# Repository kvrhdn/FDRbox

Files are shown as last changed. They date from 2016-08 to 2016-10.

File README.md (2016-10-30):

FDRbox
===
By Koenraad Verheyden - [@koenaad](https://twitter.com/koenaad)

Description
---
A simple USB MIDI controller with 8 faders.

[Album with images](http://imgur.com/a/iQqRE)

Status
---
I assembled a couple of boards and __they all work completely__!

TODO
* finish off design: find fadercaps, some screws and feet.
* clean up code.

Code
---
[```code/```](code/) is a subtree of [PIC16F145x_MIDI](https://github.com/koenaad/PIC16F145x_MIDI). The application specific code is in [```main.c```](code/main.c).

This project uses the USB stack from [Microchip Libraries for Applications](http://microchip.com/mla).  
MLA is licensed under the Apache License version 2.0. (See: [microchip.com/mla_license](http://microchip.com/mla_license))

PCB
---
[```pcb/```](pcb/) contains the schematics and design of the PCB. The entire PCB was designed using [KiCad](http://kicad-pcb.org/), an open-source software suite for EDA.

PDF's of the schematic are placed in [```pcb/output/```](pcb/output/).  
You can find the Gerber files I used here: [```pcb/output/FDRbox_v0.1_gerber/```](pcb/output/FDRbox_v0.1_gerber/)

Frontpanel
---
I also designed a frontpanel, [```frontpanel```](frontpanel/) contains the SVG I used to lasercut it.

Ableton Live MIDI Remote Script
---
[```Ableton Live MIDI Remote Script/```](Ableton Live MIDI Remote Script/) contains a MIDI Remote Script for Ableton Live. The script maps the faders to control the volume of the first 8 tracks.  
Using this script is not necessary to use FDRbox in Live (or any other DAW that supports MIDI controllers), all it does is automatically map the controls for you.

To install the script, please refer to [ableton.com: How to install a third-party Remote Script?
](https://www.ableton.com/en/help/article/install-third-party-remote-script/)

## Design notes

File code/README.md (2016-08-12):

PIC16F145x_MIDI
===
By Koenraad Verheyden - [@koenaad](https://twitter.com/koenaad)

Description
---
This project is meant to simplify designing USB MIDI controllers with the Microchip [PIC16F1454](http://www.microchip.com/wwwproducts/en/PIC16F1454) and [PIC16F1455](http://www.microchip.com/wwwproducts/en/PIC16F1455).

I chose the PIC16F145x becaues it is the smallest MCU I found capable of USB communication that doesn't need an external oscillator. [The TSSOP-14 version is really small indeed...](http://i.imgur.com/X8IG8gG.jpg)  
Additionally, Microchip sells a PDIP version which is easy to prototype with.

I made a small break-out board to experiment with this chip [[images](http://imgur.com/a/j5HQL)]. If there is interest, I am willing to post the KiCad files online or ship some of my spare PCBs.  
I'm planning to use this project as base for other MIDI controllers I design.

Usage
---
The ```system```-functions handle device initialization, configuring the USB MIDI stack and LED updates. User code can be added in ```main.c```. Usually no other files should be edited for simple applications.  
Keep in mind that no code inside the main loop may block.

To program the PIC you will probably need a [PICkit](http://www.microchip.com/Developmenttools/ProductDetails.aspx?PartNO=PG164130). Though, bootloaders could be an alternative.

MLA
---
This project uses the USB stack from [Microchip Libraries for Applications](http://microchip.com/mla).  
MLA is licensed under the Apache License version 2.0. (See: [microchip.com/mla_license](http://microchip.com/mla_license))

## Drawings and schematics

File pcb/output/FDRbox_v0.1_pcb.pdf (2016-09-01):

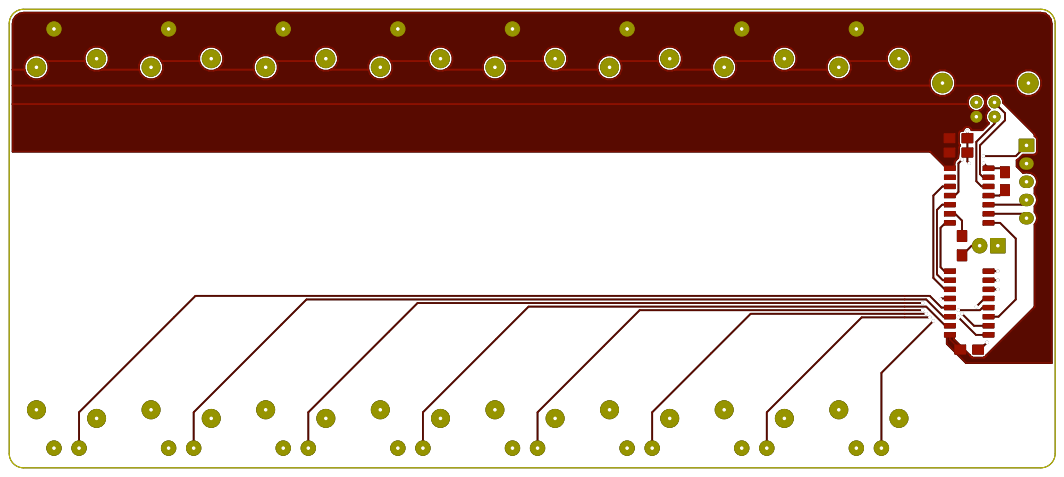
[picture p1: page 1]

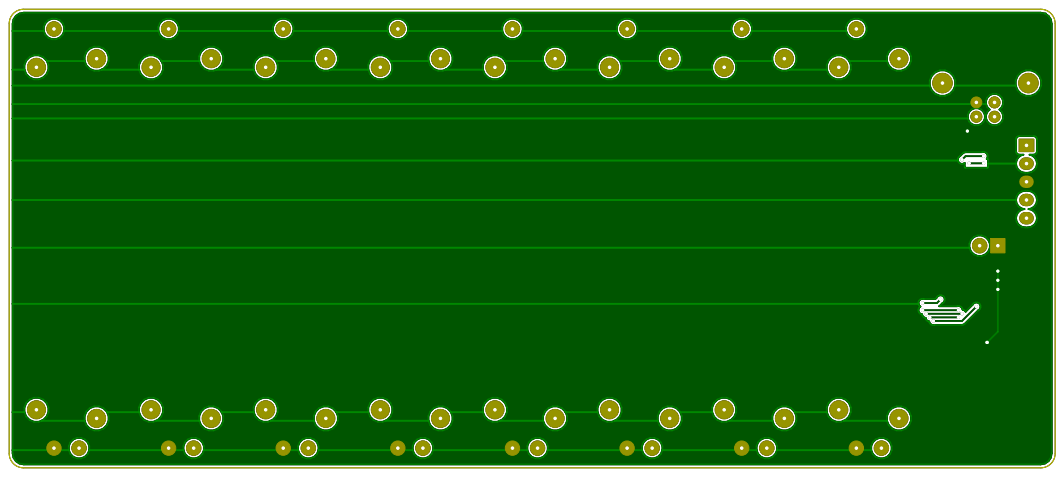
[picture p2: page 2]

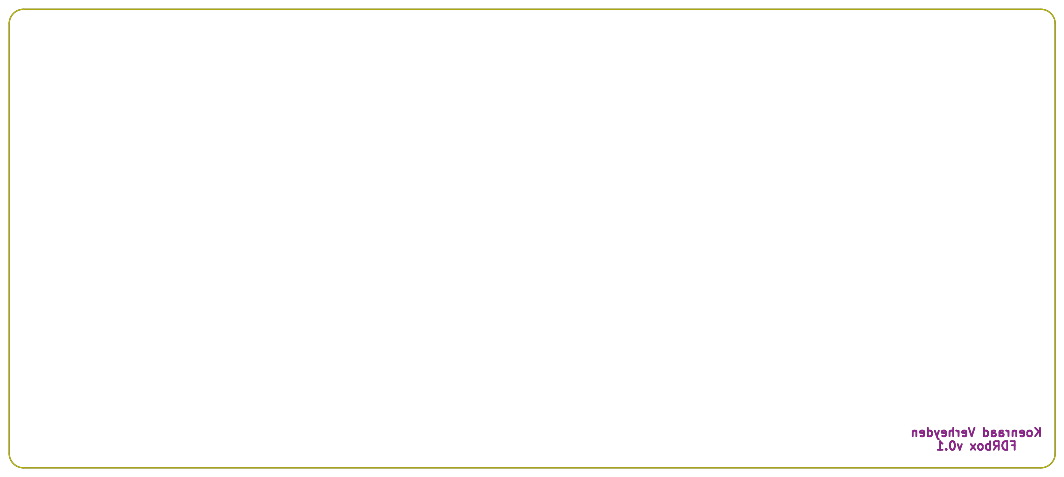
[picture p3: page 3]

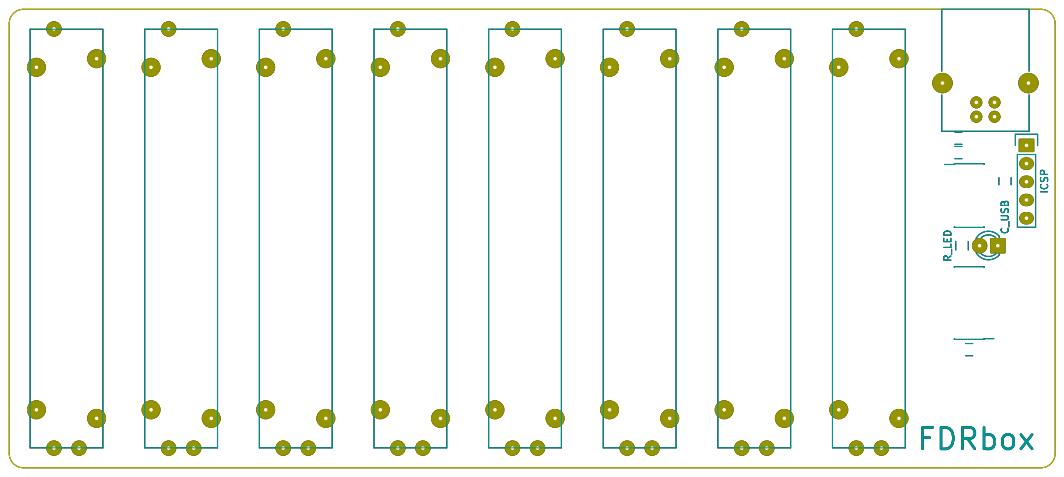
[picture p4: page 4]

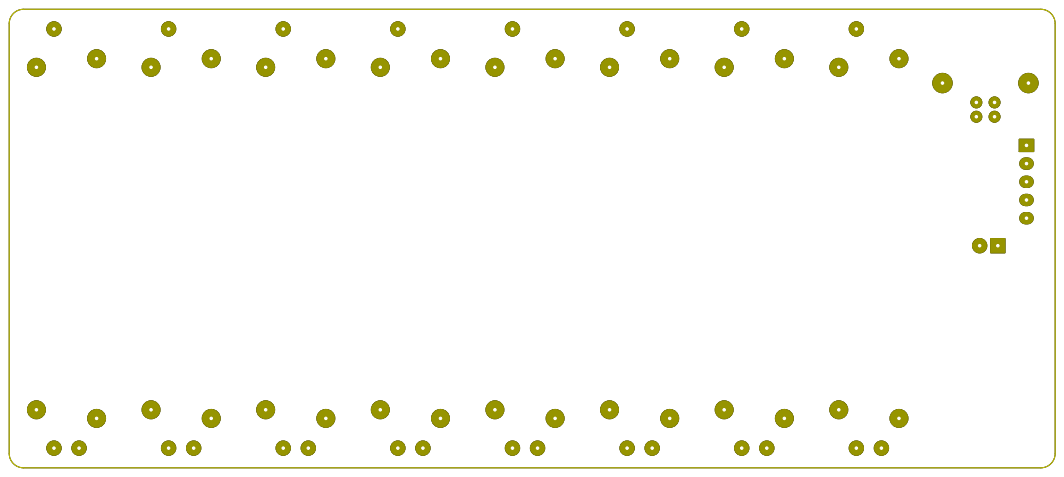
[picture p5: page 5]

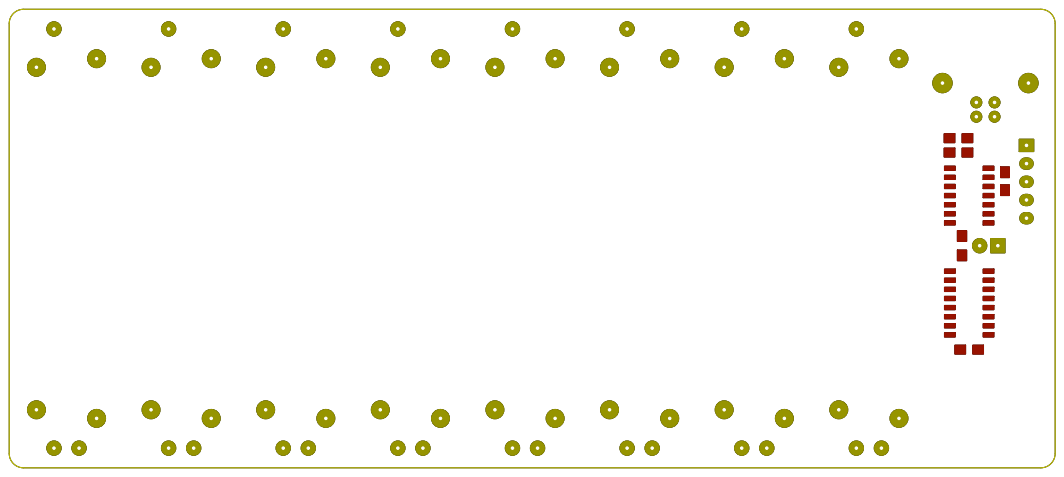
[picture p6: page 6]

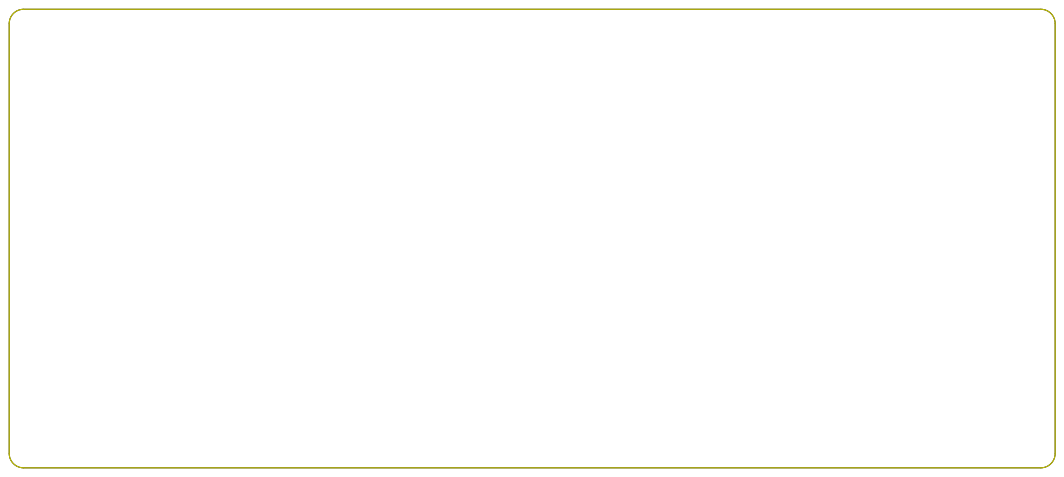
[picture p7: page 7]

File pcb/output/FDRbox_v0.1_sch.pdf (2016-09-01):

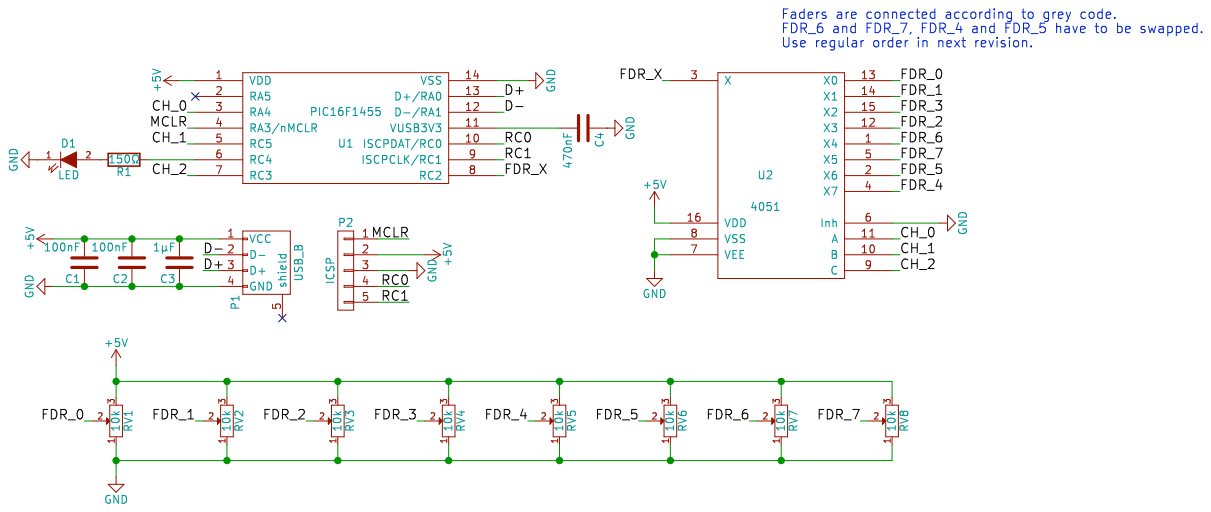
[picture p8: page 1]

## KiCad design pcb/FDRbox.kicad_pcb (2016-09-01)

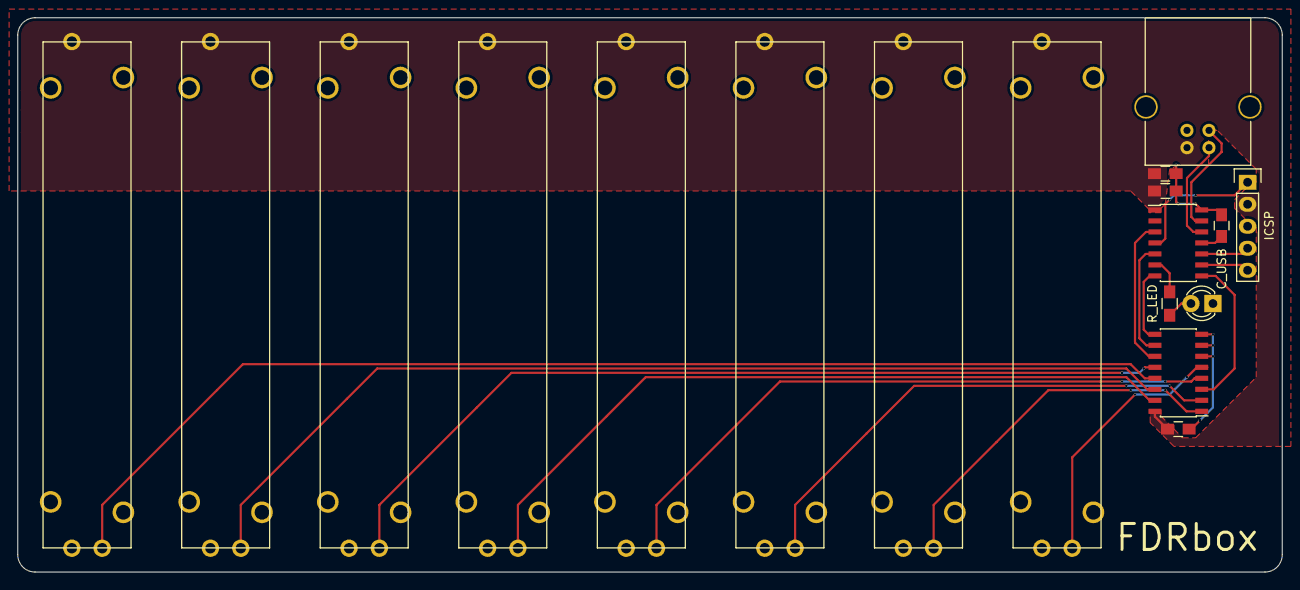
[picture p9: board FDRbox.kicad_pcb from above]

Board: 2 copper layers, 146.0 x 64.0 mm, 18 parts (0 on the bottom side), 22 nets.

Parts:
C1, C2: 100nF; C_0805_HandSoldering
C3: 1µF; C_0805_HandSoldering
C_USB: 470nF; C_0805_HandSoldering
D1: LED; LED-3MM
P1: USB_B
P2: ICSP; Pin_Header_Straight_1x05
RV1, RV2, RV3, RV4, RV5, RV6, RV7, RV8: 10k; PTA4543
R_LED: 150Ω; R_0805_HandSoldering
U1: PIC16F1455; SOIC-14_3.9x8.7mm_Pitch1.27mm
U2: 4051; SOIC-16_3.9x9.9mm_Pitch1.27mm

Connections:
+5V: C1.2, C2.2, C3.2, P1.1, P2.2, RV1.3, RV2.3, RV3.3, RV4.3, RV5.3, RV6.3, RV7.3, RV8.3, U1.1, U2.16
/CH_0: U1.3, U2.11
/CH_1: U1.5, U2.10
/CH_2: U1.7, U2.9
/D+: P1.3, U1.13
/D-: P1.2, U1.12
/FDR_0: RV1.2, U2.13
/FDR_1: RV2.2, U2.14
/FDR_2: RV3.2, U2.12
/FDR_3: RV4.2, U2.15
/FDR_4: RV5.2, U2.4
/FDR_5: RV6.2, U2.2
/FDR_6: RV7.2, U2.1
/FDR_7: RV8.2, U2.5
/FDR_X: U1.8, U2.3
/MCLR: P2.1, U1.4
/RC0: P2.4, U1.10
/RC1: P2.5, U1.9
GND: C1.1, C2.1, C3.1, C_USB.1, D1.1, P1.4, P2.3, RV1.1, RV2.1, RV3.1, RV4.1, RV5.1, RV6.1, RV7.1, RV8.1, U1.14, U2.6, U2.7, U2.8
unnamed: C_USB.2, U1.11
unnamed: D1.2, R_LED.2
unnamed: R_LED.1, U1.6

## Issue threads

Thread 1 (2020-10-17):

Need help!

4dvn, 2020-10-17:
Hello,
Can you give me the example code midi notes buttons from notes 36 to 51 of this mcu chip?

kvrhdn, 2020-10-17:
Hi, cool to see some interest!

It's been a while since I worked on this, so I'm not sure if all the tools will still work.
If I remember correctly, I've written this code using Microchip's MPLab X IDE: https://www.microchip.com/mplab/mplab-x-ide
This IDE should have support for the used PIC MCU.

The programming itself happened using a PICKit 3: https://www.microchip.com/DevelopmentTools/ProductDetails/PG164130
The PCB has a 6 pin header which can be connected to the PICKit.

You can buy an official PICKit from Microchip, but there are also cheaper clones available on AliExpress etc. that work fine as well.

> Can you give me the example code midi notes buttons from notes 36 to 51 of this mcu chip?

I'm not sure I understand your question. This MIDI controller will send MIDI CC messages when the faders change. I believe the mapping was first fader -> CC0, second fader -> CC1 etc.

4dvn, 2020-10-18:
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

thank you for looking of this old stuff ^^, my question mean that how to make button notes sent midi notes from notes 36-51, and the another issue that compile ide have error maby you can help

kvrhdn, 2020-10-18:
> my question mean that how to make button notes sent midi notes from notes 36-51

Yeah sorry, the code is a bit dense 😅 I used to write really compact and 'optimized' code before I learned to optimize for readability and understanding.

This is the code that sends a MIDI message: https://github.com/kvrhdn/FDRbox/blob/master/code/main.c#L258:L263

The key that is sent corresponds with the fader number:
```
packet.key = fdr_measurement;
```

The value is the result from the A/D converter:
```
packet.value = avg_sum;
```

So to send a different MIDI message you have to change the packet there.

> compile ide have error maby you can help

Can you post the error message? Or a screenshot? Maybe I could recognize it. But I have to warn you that it has been a while so no promises 😅

(If I may be so free,) can I ask you what you are trying to achieve? Depending on your project it might be easier to work with an  Arduino (the [Teensy has USB MIDI support for example](https://www.pjrc.com/teensy/td_midi.html)).
While this USB MIDI implementation works, I'm not sure if it is entirely according to spec and you might have to implement/fix some stuff if you need more features.

I'm currently also planning to make a USB MIDI controller using Rust based upon the STM32F0. Hopefully this will be easier to understand and extend. If that is of interest to you, you can follow my progress on Twitter: [@kvrhdn](https://twitter.com/kvrhdn).

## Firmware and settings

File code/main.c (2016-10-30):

#include <xc.h>

#include "led.h"
#include "system.h"
#include "usb_midi.h"

// TODO get 'official' VID+PID, currently using Microchip's VID. see usb_config.h

/**
 * Overview of pins capabilities (only most common used peripherals).
 * Project works with PIC16F1454 and PIC16F1455. PIC16F1459 is not tested.
 * 
 * RA0/RA1 are used for USB.
 * RA3 is used for MCLR with internal pull-up enabled.
 * RC4 is wired to the LED. Timer2 is used by the LED.
 * 
 * General purpose I/O:
 * 
 *			IOC		WPU		ICSP	SPI		I2C		PWM		ADC (1455 only)
 * RA4		x		x				SDOalt					AN3
 * RA5		x		x								PWM2alt
 * RC0						DAT		SCK		SCL				AN4
 * RC1		INT				CLK		SDI		SDA				AN5
 * RC2								SDO						AN6
 * RC3								SS				PWM2	AN7
 * RC5												PWM1
 * 
 * All weak pull-ups are enabled by default and can be independently configured
 * with WPUA.
 */

/* FDRbox
 * 
 * 8 faders are connected to an analog 8:1 MUX.
 * Analog in is connected to RC2 (AN6).
 * Channels of MUX are connected to RC3 : RC5 : RA4 (MSB -> LSB)
 * 
 * The MUX needs a certain time to switch channel, this shouldn't take longer
 * than 1 µSec (12 instructions at Fosc = 48 MHz). We assume this delay is
 * already caused by the regular code, no additional delay is implemented.
 * Caution has to be taken to not start conversion directly after switching the 
 * channel.
 * Since the ADC has some noise on the measurements, some filtering is applied.
 */

#ifndef _16F1455
#error Switch configuration to PIC16F1455 pls
#endif

/***** mux ********************************************************************/

/* The faders are connected according to grey code, so you should only need to
 * change 1 pin when scanning the channels sequentially.
 * Guess what, it only complicates stuff and mistakes are made. Not worth it.
 * 
 * Connections according to the schematic:
 * 
 * FDR_0	0	000
 * FDR_1	1	001
 * FDR_2	3	011
 * FDR_3	2	010
 * FDR_4	7	111		// FDR_4 and FDR_5 should have been switched for proper grey code
 * FDR_5	6	110
 * FDR_6	4	100		// FDR_6 and FDR_7 should have been switched for proper grey code
 * FDR_7	5	101
 * 
 * Instead of doing the grey code wiring in hardware, it could also have been
 * implemented in software by scanning the channels in a specific sequence.
 */

#define FDR_AMT	8

#define MUX_CH2	LATCbits.LATC3	// MSB
#define MUX_CH1	LATCbits.LATC5
#define MUX_CH0	LATAbits.LATA4	// LSB

static uint8_t mux_channel = 0;	// the fader currently connected

inline static
void mux_initialize()
{
	TRISCbits.TRISC3 = 0;
	TRISCbits.TRISC5 = 0;
	TRISAbits.TRISA4 = 0;

	mux_channel = 0;
	MUX_CH2 = 0;
	MUX_CH1 = 0;
	MUX_CH0 = 0;
}

/* Switch to the next channel. If this function is called FDR_AMT times every
 * fader has been chosen once.
 * Changes the variable mux_channel as well.
 */
inline static
void mux_switch_next()
{
	switch ( mux_channel ) {
		case 0:				// 000
			mux_channel = 1;// 001
//			MUX_CH2 = 0;
//			MUX_CH1 = 0;
			MUX_CH0 = 1;
			break;
		case 1:				// 001
			mux_channel = 2;// 011
//			MUX_CH2 = 0;
			MUX_CH1 = 1;
//			MUX_CH0 = 1;
			break;
		case 2:				// 011
			mux_channel = 3;// 010
//			MUX_CH2 = 0;
//			MUX_CH1 = 1;
			MUX_CH0 = 0;
			break;
		case 3:				// 010
			mux_channel = 5;// 110
			MUX_CH2 = 1;
//			MUX_CH1 = 1;
//			MUX_CH0 = 0;
			break;
		case 5:				// 110
			mux_channel = 4;// 111
//			MUX_CH2 = 1;
//			MUX_CH1 = 1;
			MUX_CH0 = 1;
			break;
		case 4:				// 111
			mux_channel = 7;// 101
//			MUX_CH2 = 1;
			MUX_CH1 = 0;
//			MUX_CH0 = 1;
			break;
		case 7:				// 101
			mux_channel = 6;// 100
//			MUX_CH2 = 1;
//			MUX_CH1 = 0;
			MUX_CH0 = 0;
			break;
		case 6:				// 100
			mux_channel = 0;// 000
			MUX_CH2 = 0;
//			MUX_CH1 = 0;
//			MUX_CH0 = 0;
			break;
	}
}

/***** data *******************************************************************/

/* Since measurements sometimes fluctuate between two values, due to noise in
 * the circuit or ADC, filtering is applied on the measurements.
 * 
 * There are two systems:
 * 
 *	-	every channel is sampled BUFFER_AVG times and the average is taken of
 *		these samples. This stabilizes measurements.
 *		If BUFFER_AVG is too high it will slow down updates.
 * 
 *	-	a buffer is kept of the last BUFFER_DEPTH transmitted values. If a new
 *		measurement is already present in the buffer, it is ignored since it was
 *		recently transmitted. This suppresses fluctuating between two values
 *		very efficiently.
 *		If BUFFER_DEPTH is too high there is a large jump in values when
 *		changing directions.
 */

#define BUFFER_AVG		2	// the amount of samples to average over, use a power of 2
#define BUFFER_DEPTH	2	// the amount of last sent values to buffer

static uint8_t avg_sum = 0;	// sum of averages, use uint16_t if BUFFER_AVG > 2
static uint8_t avg_amt = 0;	// the amount of averages taken so far

typedef struct {
	uint8_t result[ BUFFER_DEPTH ];	// circular buffer with last transmitted values
	uint8_t last_updated;			// index in result[]
} ResultBuffer;

static ResultBuffer fdr_buffer[ FDR_AMT ];

/***** main *******************************************************************/

void main( void )
{
	system_initialize();

	// initialize multiplexer
	mux_initialize();

	// initialize ADC
	TRISCbits.TRISC2 = 1;
	ANSELCbits.ANSC2 = 1;

	ADCON0bits.CHS = 6;	// RC2 = AN6
	ADCON1 = 0x60;	/* A/D control register 1
					 * 7	ADFM = 0 (left-justified, only need 7 bit)
					 * 6:4	ADCS = 110 (Fosc / 64)
					 * 3:2	x
					 * 1:0	PREF = 00 (Vref+ is connected to VDD)				*/
//	ADCON2 = 0x00;	/* A/D control register 2
//					 * 6:4	TRIGSEL = 000 (no auto-conversion)					*/

	ADCON0bits.ADON = 1;	// enable ADC

	ADCON0bits.ADGO = 1;	// start first conversion

	// update entire fdr_buffer first
	for ( uint8_t i = 0; i < FDR_AMT; ++i ) {

		while ( ADCON0bits.ADGO );	// block until conversion is done

		uint8_t measurement = ( ADRESH >> 1 );
		uint8_t fdr_measurement = mux_channel;

		mux_switch_next();

		for ( uint8_t j = 0; j < BUFFER_DEPTH; ++j )
			fdr_buffer[ fdr_measurement ].result[ j ] = measurement;
		fdr_buffer[ fdr_measurement ].last_updated = 0;

		ADCON0bits.ADGO = 1;
	}

/***** main loop **************************************************************/

	for (;;) {
		system_tasks();

		if ( ! ADCON0bits.ADGO ) {	// conversion is done

			avg_sum += ( ADRESH >> 1 );
			avg_amt += 1;

			if ( avg_amt == BUFFER_AVG ) {	// avg_sum has BUFFER_AVG samples

				// switch to next channel already - give MUX time to settle
				uint8_t fdr_measurement = mux_channel;
				mux_switch_next();

				// take average
				avg_sum /= BUFFER_AVG;

				// scan previous samples for recently transmitted values
				uint8_t i = 0;
				while ( i < BUFFER_DEPTH ) {
					if ( fdr_buffer[ fdr_measurement ].result[ i ] == avg_sum )
						break;
					++i;
				}

				if ( i == BUFFER_DEPTH ) {	// input is not yet in ResultBuffer
					// add to circular buffer
					fdr_buffer[ fdr_measurement ].result[ fdr_buffer[ fdr_measurement ].last_updated ] = avg_sum;
					fdr_buffer[ fdr_measurement ].last_updated = ( fdr_buffer[ fdr_measurement ].last_updated + 1 ) % BUFFER_DEPTH;

					// send MIDI update
					MidiPacket packet = { CONTROL_CHANGE, 0, 0 };
					packet.key = fdr_measurement;
					packet.value = avg_sum;

					midi_send( &packet, 1 );	// no error handling, packet is dropped if transmission failed
				}

				avg_sum = 0;
				avg_amt = 0;
			}

			// restart conversion
			ADCON0bits.ADGO = 1;
		}
	}
}

void midi_receive( MidiPacket packet[], uint8_t num )
{
	// ignore all incoming MIDI
}

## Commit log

2016-08-12 Implemented reading analog in + filtering
2016-08-12 Added schematic and PCB
    [FDRbox.kicad_pcb, FDRbox.sch]
2016-08-13 Squashed 'code/' changes from 8bdaec6..a0b4bef
    a0b4bef Switched LED to Timer2
    d4cd9b9 Update led.c to avoid blinking like a fool when a lot of data was sent/received
    cb998f3 I/O shouldn't default to analog in
    git-subtree-dir: code
    git-subtree-split: a0b4bef0063eeb04de062623f3766dd7959061c3
    [main.c]
2016-08-13 Started implementing switching MUX channels + organizing
2016-08-15 Implemented switching channels
2016-08-16 Added note to PCB schematic
    [FDRbox.sch]
2016-08-26 README added info PCB
2016-08-26 Clean up LED main.c
2016-08-26 Finished samples techniques - implemented double filtering technique
2016-09-01 Switch to XC8 1.38
2016-09-01 Added TODO USB VID and PID
2016-09-01 Added output files PCB
    [FDRbox-B.Cu.gbl, FDRbox-B.Mask.gbs, FDRbox-B.SilkS.gbo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]
2016-09-01 Added link to PDF schematic in README
